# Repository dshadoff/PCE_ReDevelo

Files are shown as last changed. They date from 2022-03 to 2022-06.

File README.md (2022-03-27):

# PCE_ReDevelo
A new set of hardware and support code based on Tokumashoten Intermedia's "Develo" magazines from 1996

In 1996, Tokumashoten Intermedia released several "MOOKs" (Magazine-style Books) related
to "Develo System". One for Assembler, one for BASIC, and two issues of a magazine which
followed.  The concept was that everyday users could learn how to program (or develop art
and/or music) for the PC Engine, and somehow they could eventually develop games of their own.

The "Develo System" consisted of three pieces:
1. Software on the PC Engine side (a CD-ROM included with the MOOK)
2. Software on the PC side (targetted at MSX and PC-98 series computers)
3. A small piece of hardware which was used to connect the two systems.  On the PC Engine
   side, it conected to the joypad port (while allowing pass-through for regular
   joypad use), and on the computer side, it connected to the printer port and RS-232
   port of the PC-98 (printer port and "Port2" of MSX).

Back in the day, I wasn't able to get this to work because the IBM PC systems available
in the West were not quite compatible with the PC-98. Also, I didn't know any Japanese,
and all of the documentation was in Japanese.

A version for IBM PC eventually came out, but the release packages were in an obscure
delta patch format sepcific to Japan, and the documentation was still all in Japanese.
I wasn't able to get it working to my satisfaction.

In 1998 or so, David Michel (author of the famous MagicEngine PC Engine emulator) released
an assembler package, which included some basic support for Develo, and I was able to
download the data on the disc, but I didn't do much more than that.

Years later, and computer nowadays don't normally have the same ports, and won't run the
same 16-bit progrmas from back then, so nothing from that time will work - unless you
manage to obtain old machines and put them to use.

This was the inspiration for the ReDevelo system I have created, which also consists of three pieces:
1. Software on the PC Engine side (use the original from the MOOK)
2. Software on the PC side (in Python, for flexibility)
3. A small piece of hardware to connect the two systems (and corresponding firmware).
   Plans are provided, including enough information for small-run production of the PC Boards.

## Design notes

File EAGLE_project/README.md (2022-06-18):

# PCE_ReDevelo - PC Boards

Here, you will find EAGLE project files for version of the board I have made/used.

The EAGLE project files are included, plus the gerbers and even the PCB assembly files
which might be useful for submission to JLCPCB (these are the BOM and assembly csv files).

### Revision A - Adafruit M0 Adalogger

This was the initial board I used, as I was familiar with it, and have made several designs
based on the board.  However, it has some features which I didn't end up using (and a cost
to go along with those features).

I ended up switching to the Seeeduino XIAO because this is basically a straightforward project.
So far, all code will work on both boards, but my target platform from now on will be the 'Rev B'
hardware, so this board may stop being supported at some point.

### Revision B - Seeeduino XIAO M0

As this project is straightforward, I decided to aim for a board with broad availability and
a low price (as well as a small footprint), so I chose the Seeeduino XIAO M0, which retails
for around US$5.50 .  This device is supported by the Arduino ecosystem, which is used by this
project at the current time.

In future, I may switch over to the Seeeduino XIAO RP2040 - which could sit on the same board,
but if I do that, I would port the Arduino code to the pico-sdk.

In this board revision, I have made the pads larger so that you can choose whether to mount the
XIAO M0 in a socket, or flush with the board (as the XIAO is castellated, and can be soldered
directly to the carrier board).  I also placed mounting holes in preparation for a 3D-printed
case, but have not yet designed one.  (One a case is designed, there may need to be another
board revision to accommodate the physical requirements of the case).

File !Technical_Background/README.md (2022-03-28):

# PCE_ReDevelo - Technical Background

In 1998 or so, David Michel (author of the famous MagicEngine PC Engine emulator) released
MagicKit, an assembler package, which included some basic support for Develo.

At the time when it became availbale, I was able to get it to work enough to download the data
and programs from the CD-ROM disc, but I didn't do much more than that.

But more than just include the actual command-line utilities for using Develo on an IBM PC,
David included source code to be able to build and rebuild those utilities, and to build new
functionality using the basic building blocks.

Although - or perhaps because - it doesn't actually compile or work on modern PCs, this code
was used as the basis for the current work, and I'd like to credit David with making it work,
as well as to thank the original authors of the Develo system for making it possible.

There are only a few executables included in the MagicKit set:
- GETROM : This extracts the System Card ROM from a running system into a file on the PC
- EXECMX : This will send the program and data encoded as a '.MX' file (a standard encoding
  format used for burning ROMs/PROMs back in the day), and execute it
- PERUN  : This will send the program ('.MX' as above), and execute it, but then enter 'Slave' mode,
  so that the PC will run commands requested by the PC Engine

The original system, came with several additional utilities including an assembler, a MML compiler,
and "SLAVE", a program which would put the PC Engine into slave mode so that the PC Engine could
perform commands - such as list the current directory, create a file and send data into it, etc.

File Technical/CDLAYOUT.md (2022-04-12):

# Develo CDROM layout

## Sectors

Sector 0 - Boot sector, a specific set of binary data to identify the disc as a PC Engine disc

Sector 1 - Startup sector; includes sectors to load, initial MMR settings and execute address

Sector 2 - 65 : This section is set up as a directory of files on the disc, to be accessed by
the PC host.  With each directory entry taking 32 bytes, this leaves 64 entries per sector, times
64 sectors, equals 4,096 possible files per disc.

### Directory Entries

Each directory entry is 32 bytes:
0-7: Filename
8-10: File extension
11: (if 0, ignore). If $80, audio track; otherwise data
12-13: Date bitfield.  Year = 7 MSb from 13. Month = LSb from 13, then 3 MSb from 12. Day = 5 LSb from 12
14-15: Time bitfield.  Hour = 5 MSb from 15. Minute = 3 LSb from 15, then 3 MSb from 14
If audio:
16: Track number
17-18: N/A
Else if data:
16-18: Sector number of data (18 is MSB, 16 is LSB of LBA value)
19-22: Size (22 is MSB, 19 is LSB)
23-32: Apparently unused

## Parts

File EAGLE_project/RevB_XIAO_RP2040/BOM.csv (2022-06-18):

Qty | Designator | Footprint | Comment | LCSC Part # (optional) | Description (optional)
2 | J1, J4 | 1X07_LONGPADS_OFFSET | Do not mount | Do not mount | Multi connection point. Often used as Generic Header-pin footprint for 0.1 inch spaced/style header connections
7 | C1, C2, C6, C7, C8, C9, C10 | C0402 | 100nF 16V | C1525 | Samsung CL05B104KO5NNNC 100nF 16V 0402
8 | R5, R6, R7, R8, R9, R10, R11, R12 | R0402 | 330R | C25104 | Uniroyal ElecÊ 0402WGF3300TCEÊ 0402
4 | R1, R2, R3, R4 | R0402 | 47K | C25792 | Uniroyal ElecÊ 0402WGF4702TCEÊ 0402
1 | IC3 | SOIC-16_3.9x9.9x1.27P | SN74HC157DR | C6823 | 74HC SOIC-16_150mil Signal Switches / Encoders & Decoders / Multiplexers
2 | J2, J3 | MD80SGK | Do not mount | Do not mount | Circular DIN Connectors mini-DIN, 8P jack, rt, through hole, full shield
3 | IC1, IC2, IC4 | VSSOP-8_2.0x2.3x0.5P | SN74LVC2T45DCUR | C15741 | 2-Bit Bus Transceiver, Translation VSSOP-8_2x2.3x05P SN74LVC2T45DCTR, Voltage Level Translator, Bus Transceiver LVC, 3-State 1.65

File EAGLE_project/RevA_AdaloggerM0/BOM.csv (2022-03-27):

Qty | Designator | Footprint | Comment | LCSC Part # (optional) | Description (optional)
1 | JP3 | 1X12 | Do not mount | Do not mount | Multi connection point. Often used as Generic Header-pin footprint for 0.1 inch spaced/style header connections
1 | JP1 | 1X16 | Do not mount | Do not mount | Multi connection point. Often used as Generic Header-pin footprint for 0.1 inch spaced/style header connections
7 | C1, C2, C6, C7, C8, C9, C10 | C0603 | 0.1uF 50V | C14663 | Yageo CC0603KRX7R9BB104 100NF 50V 0603
8 | R5, R6, R7, R8, R9, R10, R11, R12 | R0603 | 330 | C23138 | Uniroyal Elec 0603WAF3300T5E 0603
4 | R1, R2, R3, R4 | R0603 | 47K | C25819 | Uniroyal Elec 0603WAF4702T5E 0603
1 | IC3 | SOIC-16_3.9x9.9x1.27P | SN74HC157DR | C6823 | 74HC SOIC-16_150mil Signal Switches / Encoders & Decoders / Multiplexers
2 | J2, J3 | MD80SGK | Do not mount | Do not mount | Circular DIN Connectors mini-DIN, 8P jack, rt, through hole, full shield
3 | IC1, IC2, IC4 | VSSOP-8_2.0x2.3x0.5P | SN74LVC2T45DCUR | C15741 | 2-Bit Bus Transceiver, Translation VSSOP-8_2x2.3x05P SN74LVC2T45DCTR, Voltage Level Translator, Bus Transceiver LVC, 3-State 1.65

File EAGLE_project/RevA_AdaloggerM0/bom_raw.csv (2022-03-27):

Qty | Value | Device | Package | Parts | Description
1 |  | HEADER-1X12 | 1X12_ROUND | JP3
1 |  | HEADER-1X16ROUND | 1X16_ROUND | JP1 | PIN HEADER
7 | 0.1uF | C-USC0603 | C0603 | C1, C2, C6, C7, C8, C9, C10 | CAPACITOR, American symbol
8 | 300 | R-US_R0603 | R0603 | R5, R6, R7, R8, R9, R10, R11, R12 | RESISTOR, American symbol
4 | 47K | R-US_R0603 | R0603 | R1, R2, R3, R4 | RESISTOR, American symbol
1 | MC74HC157ADG | MC74HC157ADG | SOIC127P600X175-16N | IC3 | Source: Datasheet
2 | MD-80SGK | MD-80SGK | MD80SGK | J2, J3 | Circular DIN Connectors mini-DIN, 8P jack, rt, through hole, full shield
3 | SN74LVC2T45DCUR | SN74LVC2T45DCUR | SOP50P310X90-8N | IC1, IC2, IC4 | Texas Instruments SN74LVC2T45DCUR, Voltage Level Translator, Bus Transceiver, 3-State, 1.65 5.5 V, 8-Pin UM

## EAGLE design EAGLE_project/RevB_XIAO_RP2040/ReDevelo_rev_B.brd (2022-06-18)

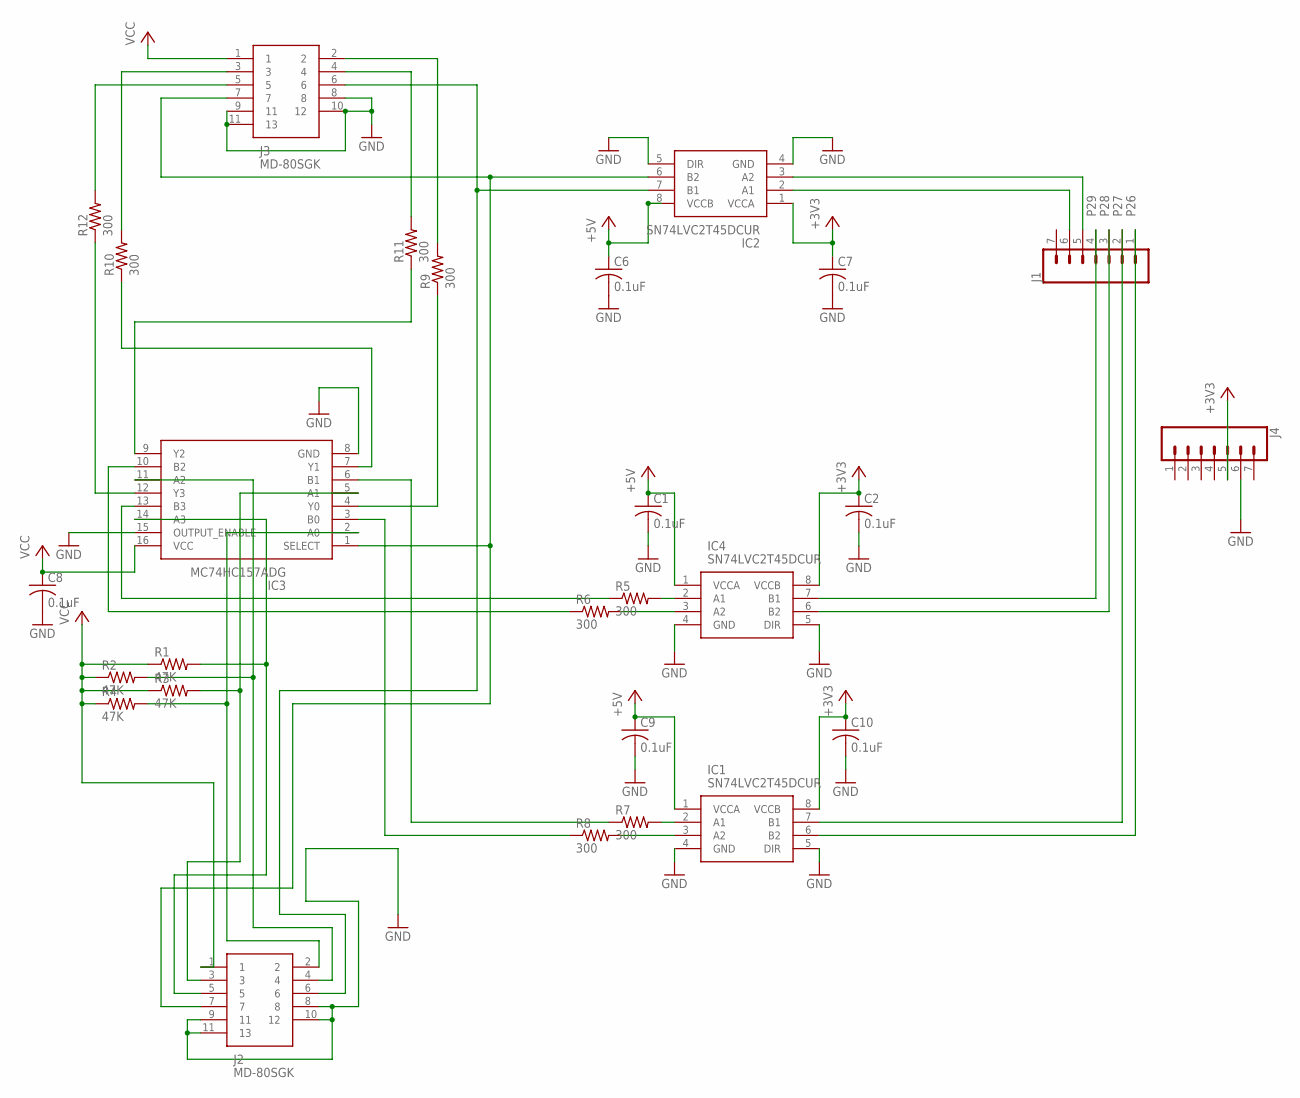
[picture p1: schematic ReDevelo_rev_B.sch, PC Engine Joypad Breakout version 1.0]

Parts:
C1, C2, C6, C7, C8, C9, C10: 0.1uF; C0402
IC1, IC2, IC4: SN74LVC2T45DCUR; SOP50P310X90-8N
IC3: MC74HC157ADG; SOIC127P600X175-16N
J1, J4: CONN_071X07_LONGPADS_OFFSET; 1X07_LONGPADS_OFFSET
J2, J3: MD-80SGK; MD80SGK
R1, R2, R3, R4: 47K; R0402
R5, R6, R7, R8, R9, R10, R11, R12: 300; R0402

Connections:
+3V3: C2.1, C7.1, C10.1, IC1.8 (VCCB), IC2.1 (VCCA), IC4.8 (VCCB), J4.5
CLR: IC2.6 (B2), IC3.1 (SELECT), J2.7, J3.7
D12: IC2.2 (A1), J1.6
D13: IC2.3 (A2), J1.5
GND: C1.2, C2.2, C6.2, C7.2, C8.2, C9.2, C10.2, IC1.4 (GND), IC1.5 (DIR), IC2.4 (GND), IC2.5 (DIR), IC3.8 (GND), IC3.15 (OUTPUT_ENABLE), IC4.4 (GND), IC4.5 (DIR), J2.8, J2.9 (11), J2.10 (12), J2.11 (13), J3.8, J3.9 (11), J3.10 (12), J3.11 (13), J4.6
unnamed: IC3.5 (A1), J2.3, R3.2
unnamed: IC3.2 (A0), J2.2, R4.2
unnamed: IC3.11 (A2), J2.4, R2.2
unnamed: IC3.14 (A3), J2.5, R1.2
unnamed: IC3.12 (Y3), R12.1
unnamed: IC3.9 (Y2), R11.1
unnamed: IC3.13 (B3), R5.1
unnamed: IC3.7 (Y1), R10.1
unnamed: IC4.2 (A1), R5.2
unnamed: IC4.3 (A2), R6.2
unnamed: IC1.3 (A2), R8.2
unnamed: IC1.2 (A1), R7.2
unnamed: IC3.10 (B2), R6.1
unnamed: IC3.3 (B0), R8.1
unnamed: IC3.6 (B1), R7.1
unnamed: J3.2, R9.2
unnamed: J3.4, R11.2
unnamed: IC3.4 (Y0), R9.1
unnamed: J3.3, R10.2
unnamed: J3.5, R12.2
P26: IC1.6 (B2), J1.1
P27: IC1.7 (B1), J1.2
P28: IC4.6 (B2), J1.3
P29: IC4.7 (B1), J1.4
SEL: IC2.7 (B1), J2.6, J3.6
VCC: C1.1, C6.1, C8.1, C9.1, IC1.1 (VCCA), IC2.8 (VCCB), IC3.16 (VCC), IC4.1 (VCCA), J2.1, J3.1, R1.1, R2.1, R3.1, R4.1

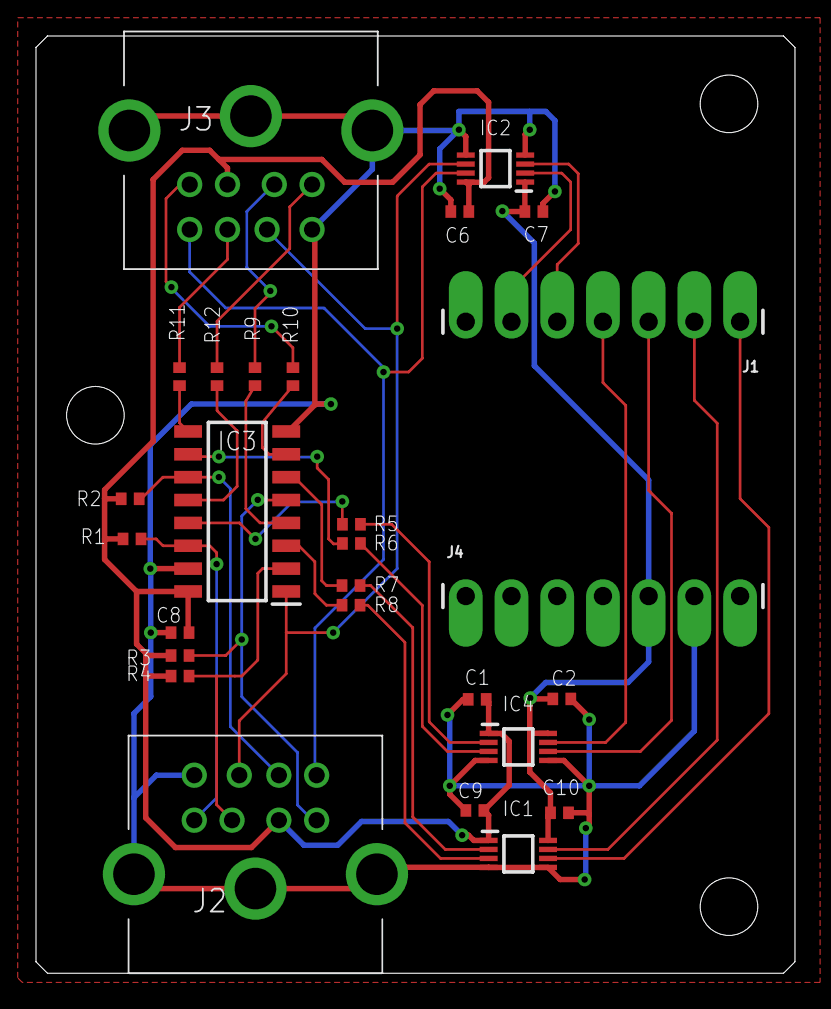
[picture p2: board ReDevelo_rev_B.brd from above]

Board: 2 copper layers, 42.2 x 52.1 mm, 27 parts (0 on the bottom side), 31 nets.

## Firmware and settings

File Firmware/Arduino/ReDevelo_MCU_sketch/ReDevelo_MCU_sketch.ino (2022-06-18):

/*
  ReDevelo_MCU_sketch

  On most boards (including the Adafruit M0 Adalogger), "Serial" refers to the USB
  Serial port attached to the Serial Monitor, and "Serial1" refers to the hardware
  serial port attached to pins 0 and 1. This sketch will emulate Serial passthrough
  using those two Serial ports on the boards mentioned above, but you can change
  these names to connect any two serial ports on a board that has multiple ports.

  This version of the sketch is intended for "rev. A" of the board

  (c) 2022 by David Shadoff
*/


#include "define.h"
#include "develo.h"


void setup()
{
  int i;
  char c;
  unsigned char bankbuf[8];
  unsigned char buf[4096];
  char outbuf[128];
  unsigned long startTime, endTime;

  // setup Serial ports
  Serial.begin(19200);  // computer side

  // setup GPIO pins
  pinMode(d0_Pin,   OUTPUT);
  pinMode(d1_Pin,   OUTPUT);
  pinMode(d2_Pin,   OUTPUT);
  pinMode(d3_Pin,   OUTPUT);
  pinMode(selPin,   INPUT);
  pinMode(clrPin,   INPUT);
  
//  pinMode(TriggerPin, INPUT_PULLUP);

  pinMode(LED_Pin,  OUTPUT);

  // set default values on outputs
  //
  write_PCE_port(0x0F);

  delay(4000);  // wait for startup period


  Serial.println("Initializing Develo...");
  if (dv_init() != DV_OK) {
    Serial.println("Can not initialize the ReDevelo box!");
//    exit(1);
  }

  for (i =0; i < 8; i++) {
    bankbuf[i] = 0x00;
  }
}


// ------------------
void serial_setbank() {
int retcode;
int page;
int bank;

  while (!Serial.available());    // need to wait for data to be available
  page = Serial.read();

  while (!Serial.available());    // need to wait for data to be available
  bank = Serial.read();

  retcode = dv_set_bank(page, bank);
  Serial.write(retcode);
  Serial.flush();
}

void serial_getbank() {
int retcode;
unsigned char bankbuf[16];

  for (int i =0; i < 8; i++) {
    bankbuf[i] = 0x00;
  }
  retcode = dv_get_bank(bankbuf);
  if (retcode != DV_OK) {
    Serial.write(retcode);
    Serial.flush();
  }
  else {
    Serial.write(retcode);
    Serial.write(bankbuf,8);
    Serial.flush();
  }
}

void serial_getram() {
int retcode;
unsigned char buf[1024];
int addr_h, addr_l, len_h, len_l;
int addr, len;
int i;

  while (!Serial.available());    // need to wait for data to be available
  addr_h = Serial.read();
  while (!Serial.available());    // need to wait for data to be available
  addr_l = Serial.read();

  while (!Serial.available());    // need to wait for data to be available
  len_h = Serial.read();
  while (!Serial.available());    // need to wait for data to be available
  len_l = Serial.read();

  addr = (addr_h << 8) + addr_l;
  len  = (len_h  << 8) + len_l;
  
  if (len > 512) len = 512;

  retcode = dv_get_ram(buf, addr, len);
  if (retcode != DV_OK) {
    Serial.write(retcode);
    Serial.flush();
  }
  else {
    Serial.write(retcode);
    for (i = 0 ; i < len; i++) {
      Serial.write(*(buf+i));
    }
    Serial.flush();
  }
}

void serial_setram() {
int retcode;
unsigned char buf[1024];
int addr_h, addr_l, len_h, len_l;
int addr, len;
int i;

  while (!Serial.available());    // need to wait for data to be available
  addr_h = Serial.read();
  while (!Serial.available());    // need to wait for data to be available
  addr_l = Serial.read();

  while (!Serial.available());    // need to wait for data to be available
  len_h = Serial.read();
  while (!Serial.available());    // need to wait for data to be available
  len_l = Serial.read();

  addr = (addr_h << 8) + addr_l;
  len  = (len_h  << 8) + len_l;
  
  if (len > 512) len = 512;
  
  for (i = 0 ; i < len; i++) {
    while (!Serial.available());    // need to wait for data to be available
    *(buf+i) = Serial.read();
  }

  retcode = dv_set_ram(addr, buf, len);
  Serial.write(retcode);
  Serial.flush();
}

void serial_getvram() {
int retcode;
unsigned char buf[1024];
int addr_h, addr_l, len_h, len_l;
int addr, len;
int i;

  while (!Serial.available());    // need to wait for data to be available
  addr_h = Serial.read();
  while (!Serial.available());    // need to wait for data to be available
  addr_l = Serial.read();

  while (!Serial.available());    // need to wait for data to be available
  len_h = Serial.read();
  while (!Serial.available());    // need to wait for data to be available
  len_l = Serial.read();

  addr = (addr_h << 8) + addr_l;
  len  = (len_h  << 8) + len_l;
  
  if (len > 512) len = 512;

  retcode = dv_get_vram(buf, addr, len);
  if (retcode != DV_OK) {
    Serial.write(retcode);
  }
  else {
    Serial.write(retcode);
    for (i = 0 ; i < len; i++) {
      Serial.write(*(buf+i));
    }
    Serial.flush();
  }
}

void serial_setvram() {
int retcode;
unsigned char buf[1024];
int addr_h, addr_l, len_h, len_l;
int addr, len;
int i;

  while (!Serial.available());    // need to wait for data to be available
  addr_h = Serial.read();
  while (!Serial.available());    // need to wait for data to be available
  addr_l = Serial.read();

  while (!Serial.available());    // need to wait for data to be available
  len_h = Serial.read();
  while (!Serial.available());    // need to wait for data to be available
  len_l = Serial.read();

  addr = (addr_h << 8) + addr_l;
  len  = (len_h  << 8) + len_l;
  
  if (len > 512) len = 512;
  
  for (i = 0 ; i < len; i++) {
    while (!Serial.available());    // need to wait for data to be available
    *(buf+i) = Serial.read();
  }

  retcode = dv_set_vram(addr, buf, len);
  Serial.write(retcode);
  Serial.flush();
}

void serial_getcolor() {
int retcode;
unsigned char buf[1024];
int addr_h, addr_l, len_h, len_l;
int addr, len;
int i;

  while (!Serial.available());    // need to wait for data to be available
  addr_h = Serial.read();
  while (!Serial.available());    // need to wait for data to be available
  addr_l = Serial.read();

  while (!Serial.available());    // need to wait for data to be available
  len_h = Serial.read();
  while (!Serial.available());    // need to wait for data to be available
  len_l = Serial.read();

  addr = (addr_h << 8) + addr_l;
  len  = (len_h  << 8) + len_l;
  
  if (len > 512) len = 512;

  retcode = dv_get_color(buf, addr, len);
  if (retcode != DV_OK) {
    Serial.write(retcode);
  }
  else {
    Serial.write(retcode);
    for (i = 0 ; i < len; i++) {
      Serial.write(*(buf+i));
    }
    Serial.flush();
  }
}

void serial_setcolor() {
int retcode;
unsigned char buf[1024];
int addr_h, addr_l, len_h, len_l;
int addr, len;
int i;

  while (!Serial.available());    // need to wait for data to be available
  addr_h = Serial.read();
  while (!Serial.available());    // need to wait for data to be available
  addr_l = Serial.read();

  while (!Serial.available());    // need to wait for data to be available
  len_h = Serial.read();
  while (!Serial.available());    // need to wait for data to be available
  len_l = Serial.read();

  addr = (addr_h << 8) + addr_l;
  len  = (len_h  << 8) + len_l;
  
  if (len > 512) len = 512;
  
  for (i = 0 ; i < len; i++) {
    while (!Serial.available());    // need to wait for data to be available
    *(buf+i) = Serial.read();
  }

  retcode = dv_set_color(addr, buf, len);
  Serial.write(retcode);
  Serial.flush();
}

void serial_exec() {
int retcode;
unsigned char buf[1024];
int addr_h, addr_l;
int addr;
int i;

  while (!Serial.available());    // need to wait for data to be available
  addr_h = Serial.read();
  while (!Serial.available());    // need to wait for data to be available
  addr_l = Serial.read();

  addr = (addr_h << 8) + addr_l;

  retcode = dv_exec(addr, 0);
  Serial.write(retcode);
  Serial.flush();
}

void serial_getCDsector() {
int retcode;
unsigned char buf[3072];
int sector_h, sector_m, sector_l;
int sector;
int i;

  while (!Serial.available());    // need to wait for data to be available
  sector_h = Serial.read();
  while (!Serial.available());    // need to wait for data to be available
  sector_m = Serial.read();
  while (!Serial.available());    // need to wait for data to be available
  sector_l = Serial.read();

  sector = (sector_h << 16) + (sector_m << 8) + sector_l;
  
  retcode = dv_read_cd(buf, sector);
  if (retcode != DV_OK) {
    Serial.write(retcode);
    Serial.flush();
  }
  else {
    Serial.write(retcode);
    for (i = 0 ; i < 2048; i++) {
      Serial.write(*(buf+i));
    }
    Serial.flush();
  }
}

void serial_error() {
    Serial.write(DV_INTERNAL_ERR);
    Serial.flush();
}

// -------------------
void loop() {
int c;
int numbytes, readsize, bytesread;
boolean flush = false;
char buffer[49];
static bool led_state = LOW;

  while (!Serial.available());  // wait for input

  c = Serial.read();
  switch(c) {
    case 'A':   // set bank
        serial_setbank();
        led_state = led_state ? LOW : HIGH;
        digitalWrite(LED_Pin, led_state);
        break;

    case 'B':   // get bank
        serial_getbank();
        led_state = led_state ? LOW : HIGH;
        digitalWrite(LED_Pin, led_state);
        break;

    case 'D':   // get ram
        serial_getram();
        led_state = led_state ? LOW : HIGH;
        digitalWrite(LED_Pin, led_state);
        break;

    case 'E':   // set ram
        serial_setram();
        led_state = led_state ? LOW : HIGH;
        digitalWrite(LED_Pin, led_state);
        break;
        
    case 'F':   // get vram
        serial_getvram();
        led_state = led_state ? LOW : HIGH;
        digitalWrite(LED_Pin, led_state);
        break;

    case 'G':   // set vram
        serial_setvram();
        led_state = led_state ? LOW : HIGH;
        digitalWrite(LED_Pin, led_state);
        break;

    case 'H':   // get color
        serial_getcolor();
        led_state = led_state ? LOW : HIGH;
        digitalWrite(LED_Pin, led_state);
        break;

    case 'I':   // set color
        serial_setcolor();
        led_state = led_state ? LOW : HIGH;
        digitalWrite(LED_Pin, led_state);
        break;

    case 'J':   // execute
        serial_exec();
        led_state = led_state ? LOW : HIGH;
        digitalWrite(LED_Pin, led_state);
        break;

    case 'L':   // read CD sector
        serial_getCDsector();
        led_state = led_state ? LOW : HIGH;
        digitalWrite(LED_Pin, led_state);
        break;

    case 'Z':   // error
        serial_error();
        led_state = led_state ? LOW : HIGH;
        digitalWrite(LED_Pin, led_state);
        break;

    default:
      break;
  }
  
}

//
// hex conversion routines
//
// char hex2digit(char *buffer)
//   - take a single char of buffer, return val (0-15) in char
//
// char hex2digit(char *buffer)
//   - take 2 chars of buffer, turn it into a char
//
// int hextoint16(char *buffer)
//   - take 4 chars of buffer, turn it into an int
//
// hex2tobuf(char c, char *buffer)
//   - take char and 'sprintf' it as 2-bute hex string into buffer
//
// hex4tobuf(int i, char *buffer)
//   - take int and 'sprintf' it as 4-bute hex string into buffer
//
char hex2digit(char *buffer) {
char c, n;

  c = *buffer;

  if ((c >= '0') && (c <= '9')) {
    n = c - '0';
  }
  else if ((c >= 'A') && (c <= 'F')) {
    n = c - 'A' + 10;
  }
  else if ((c >= 'a') && (c <= 'f')) {
    n = c - 'a' + 10;
  }
  else
    n = 0;

  return(n);
}

char hextobyte(char *buffer) {
char n;

  n = (hex2digit(buffer) << 4);
  buffer++;
  n |= hex2digit(buffer);

  return(n);
}

int hextoint16(char *buffer) {
int n;

  n = (hex2digit(buffer) << 12);
  buffer++;
  n |= (hex2digit(buffer) << 8);
  buffer++;
  n |= (hex2digit(buffer) << 4);
  buffer++;
  n |= hex2digit(buffer);

  return(n);
}


//
// printhex2(char) / printhex4(int)
// 
// Print a char variable as a 2-/4-digit hex number
//
// Arduino has a print(... , HEX) function, but it trims leading zeroes
// which is not desirable.  Have to break it down to character-by-character
//
void printhex2(char c)
{
int c1, c2;

  c1 = (c >> 4) & 0x0f;
  c2 = c & 0x0f;

  Serial.print(c1, HEX);
  Serial.print(c2, HEX);
}

void printhex4(int i)
{
int c1, c2, c3, c4;

  c1 = (i >> 12) & 0x0f;
  c2 = (i >> 8) & 0x0f;
  c3 = (i >> 4) & 0x0f;
  c4 = i & 0x0f;
  
  Serial.print(c1, HEX);
  Serial.print(c2, HEX);
  Serial.print(c3, HEX);
  Serial.print(c4, HEX);
}


void hex2tobuf(char c, char *buffer)
{
  int c1, c2;
  c1 = c / 16;
  c2 = c % 16;

  if (c1 < 0x0a)
    *buffer = c1 + '0';
  else
    *buffer = (c1 - 10) + 'A';

  buffer++;

  if (c2 < 0x0a)
    *buffer = c2 + '0';
  else
    *buffer = (c2 - 10) + 'A';
}

void hex4tobuf(int i, char *buffer)
{
char c;

  c = i >> 8;
  hex2tobuf(c, buffer);

  buffer += 2;

  c = i & 0xff;
  hex2tobuf(c, buffer);
}

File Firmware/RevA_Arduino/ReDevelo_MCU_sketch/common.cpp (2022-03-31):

//
// common.c
//
// This file contains all sorts of common utility routines, such as
// string/hex conversion, serial I/O and buffer control, etc.
//
// (c) 2022 by David Shadoff


#include <Arduino.h>
#include <SD.h>
#include "crc16.h"
#include "develo.h"

#define DELAY_MICROS  1

#define IN_PORT            REG_PORT_IN0
#define IN_CLR             PORT_PA17          // Pin marked as D13 on M0 Feather Adalogger (CLR on PCE joypad)
#define IN_SEL             PORT_PA19          // Pin marked as D12 on M0 Feather Adalogger (SEL on PCE joypad)
#define OUT_PORT_SET       REG_PORT_OUTSET0
#define OUT_PORT_CLR       REG_PORT_OUTCLR0
#define OUT_D3             PORT_PA16          // Pin marked as D11 on M0 Feather Adalogger (D3 on PCE joypad)
#define OUT_D2             PORT_PA18          // Pin marked as D10 on M0 Feather Adalogger (D2 on PCE joypad)
#define OUT_D1             PORT_PA20          // Pin marked as D6  on M0 Feather Adalogger (D1 on PCE joypad)
#define OUT_D0             PORT_PA15          // Pin marked as D5  on M0 Feather Adalogger (D0 on PCE joypad)

const int clrPin      = 13;  // CLR signal from PCE (Develo) (CLR)
const int selPin      = 12;  // SEL signal from PCE (Develo) (SEL)

const int d3_Pin      = 11;  // data 3 to PCE
const int d2_Pin      = 10;  // data 2 to PCE
const int d1_Pin      = 6;   // data 1 to PCE
const int d0_Pin      = 5;   // data 0 to PCE

const int LED_Pin     = 8;   // green LED

//
// DEVELO initialization stuff:
//

// ALREADY COVERED:
//
// CRC16.H
// DEVELO.H
// ERROR.C
// INIT.C
// COMMAND.C
// 
// MAKE MINOR CORRECTIONS (TODO) TO:  (kbhit & delay timing)
// XFER.C
//
// NEXT UP:
// --------
// SLAVE.C
// GETROM.C
// PERUN.C
// MX.C
// EXECMX.C


int develo = 1;      /* develo box presence flag */


int develo_wait1 = 20000; /* timeout retries */
int develo_wait2 = 20000;
int develo_error; /* latest error */
int develo_status;  /* transfer status */
int slave_mode;
int slave_wait;

static int  dv_crc(unsigned char *buf, int len);
static int  dv_request(int cmd);
static void dv_output(int data);
static int  dv_output_and_wait(int c, int val);
static int  dv_input(void);
static void dv_delay(void);

// static void write_PCE_port(int value);
static int  read_PCE_port(void);


/*************  COMMAND.C  **************/

/* ----
 * dv_set_bank()
 * ----
 */

int
dv_set_bank(int page, int bank)
{
  unsigned char buf[8];

  buf[0] = 2;
  buf[1] = page;
  buf[2] = bank;
  buf[3] = 0;
  buf[4] = 0;
  buf[5] = 0;
  buf[6] = 0;
  buf[7] = 0;
  
  if (dv_send_cmd(buf) != DV_OK)
    return (DV_ERR);
  
  return (DV_OK);
}


/* ----
 * dv_get_bank()
 * ----
 */

int
dv_get_bank(unsigned char *bank)
{
  unsigned char buf[8];

  buf[0] = 3;
  buf[1] = 0;
  buf[2] = 0;
  buf[3] = 0;
  buf[4] = 0;
  buf[5] = 0;
  buf[6] = 0;
  buf[7] = 0;
  
  if (dv_send_cmd(buf) != DV_OK)
    return (DV_ERR);
  if (dv_recv_block(buf, 8) != DV_OK)
    return (DV_ERR);

  memcpy(bank, buf, 8);
  return (DV_OK);
}


/* ----
 * dv_get_ram()
 * ----
 * transfer a block of memory from the PC Engine to the PC
 */

int
dv_get_ram(unsigned char *data, int addr, int len)
{
  unsigned char buf[8];

  buf[0] = 4;
  buf[1] = (addr & 0xFF00) >> 8;
  buf[2] = (addr & 0x00FF);
  buf[3] = (len  & 0xFF00) >> 8;
  buf[4] = (len  & 0x00FF);
  buf[5] = 0;
  buf[6] = 0;
  buf[7] = 0;

  if (dv_send_cmd(buf) != DV_OK)
    return (DV_ERR);
  if (dv_recv_block(data, len) != DV_OK)
    return (DV_ERR);
  
  return (DV_OK);
}


/* ----
 * dv_set_ram()
 * ----
 * transfer a block of memory from the PC to the PC Engine
 */

int
dv_set_ram(int addr, unsigned char *data, int len)
{
  unsigned char buf[8];
  int size, pos, temp;
  
  size = len;
  pos = 0;

  /* transfer the block by chunk of 512 bytes */
  while (size) {
    temp = (size > 512) ? 512 : size;

    buf[0] = 5;
    buf[1] = ((addr + pos) & 0xFF00) >> 8;
    buf[2] = ((addr + pos) & 0x00FF);
    buf[3] = (temp & 0xFF00) >> 8;
    buf[4] = (temp & 0x00FF);
    buf[5] = 0;
    buf[6] = 0;
    buf[7] = 0;
  
    if (dv_send_cmd(buf) != DV_OK)
      return (DV_ERR);
    if (dv_send_block(&data[pos], temp) != DV_OK)
      return (DV_ERR);
    if (dv_wait_ack() != DV_OK)
      return (DV_ERR);

    size -= temp;
    pos  += temp;
  }
  
  return (DV_OK);
}


/* ----
 * dv_get_vram()
 * ----
 */

int
dv_get_vram(unsigned char *data, int addr, int len)
{
  unsigned char buf[8];
  int size, pos, temp;
  
  size = len;
  pos = 0;

  /* get the block by chunk of 512 bytes */
  while (size) {
    temp = (size > 512) ? 512 : size;

    buf[0] = 6;
    buf[1] = ((addr + (pos / 2)) & 0xFF00) >> 8;
    buf[2] = ((addr + (pos / 2)) & 0x00FF);
    buf[3] = (temp & 0xFF00) >> 8;
    buf[4] = (temp & 0x00FF);
    buf[5] = 0;
    buf[6] = 0;
    buf[7] = 0;
  
    if (dv_send_cmd(buf) != DV_OK)
      return (DV_ERR);
    if (dv_recv_block(&data[pos], temp) != DV_OK)
      return (DV_ERR);

    size -= temp;
    pos  += temp;
  }

  return (DV_OK);
} 


/* ----
 * dv_set_vram()
 * ----
 */

int
dv_set_vram(int addr, unsigned char *data, int len)
{
  unsigned char buf[8];
  int size, pos, temp;
  
  size = len;
  pos = 0;

  /* transfer the block by chunk of 512 bytes */
  while (size) {
    temp = (size > 512) ? 512 : size;

    buf[0] = 7;
    buf[1] = ((addr + (pos / 2)) & 0xFF00) >> 8;
    buf[2] = ((addr + (pos / 2)) & 0x00FF);
    buf[3] = (temp & 0xFF00) >> 8;
    buf[4] = (temp & 0x00FF);
    buf[5] = 0;
    buf[6] = 0;
    buf[7] = 0;
  
    if (dv_send_cmd(buf) != DV_OK)
      return (DV_ERR);
    if (dv_send_block(&data[pos], temp) != DV_OK)
      return (DV_ERR);
    if (dv_wait_ack() != DV_OK)
      return (DV_ERR);

    size -= temp;
    pos  += temp;
  }
  
  return (DV_OK);
}


/* ----
 * dv_get_color()
 * ----
 */

int
dv_get_color(unsigned char *data, int addr, int len)
{
  unsigned char buf[8];

  buf[0] = 8;
  buf[1] = (addr & 0xFF00) >> 8;
  buf[2] = (addr & 0x00FF);
  buf[3] = (len & 0xFF00) >> 8;
  buf[4] = (len & 0x00FF);
  buf[5] = 0;
  buf[6] = 0;
  buf[7] = 0;

  if (dv_send_cmd(buf) != DV_OK)
    return (DV_ERR);
  if (dv_recv_block(data, len) != DV_OK)
    return (DV_ERR);
  
  return (DV_OK);
}


/* ----
 * dv_set_color()
 * ----
 */

int
dv_set_color(int addr, unsigned char *data, int len)
{
  unsigned char buf[8];

  buf[0] = 9;
  buf[1] = (addr & 0xFF00) >> 8;
  buf[2] = (addr & 0x00FF);
  buf[3] = (len & 0xFF00) >> 8;
  buf[4] = (len & 0x00FF);
  buf[5] = 0;
  buf[6] = 0;
  buf[7] = 0;

  if (dv_send_cmd(buf) != DV_OK)
    return (DV_ERR);
  if (dv_send_block(data, len) != DV_OK)
    return (DV_ERR);
  if (dv_wait_ack() != DV_OK)
    return (DV_ERR);
  
  return (DV_OK);
}


/* ----
 * dv_exec()
 * ----
 * execute the program starting at <addr> on the PC Engine
 */
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

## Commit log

2022-03-27 Initial Check-in
    [BOM.csv, ReDevelo_rev_A.brd, ReDevelo_rev_A.mnt.csv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]
2022-03-31 Add exec() and getsector() functions, add a couple of test programs
2022-04-01 Clean up Arduino code
2022-06-18 Update for Seeeduino XIAO version
    [BOM.csv, ReDevelo_rev_B.brd, ReDevelo_rev_B.sch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]

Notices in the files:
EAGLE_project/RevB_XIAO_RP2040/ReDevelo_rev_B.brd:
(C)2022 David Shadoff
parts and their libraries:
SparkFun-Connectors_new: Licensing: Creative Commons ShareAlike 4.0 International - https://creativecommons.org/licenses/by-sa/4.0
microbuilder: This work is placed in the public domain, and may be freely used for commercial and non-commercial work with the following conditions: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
